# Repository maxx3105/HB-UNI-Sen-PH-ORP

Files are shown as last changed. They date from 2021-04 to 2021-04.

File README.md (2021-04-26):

# HB-UNI-Sen-PH-ORP
HomeMatic PH- und Redox-Sensor

Dieses Projekt basiert auf der Arbeit von [pa-pa](https://github.com/pa-pa/AskSinPP) ,[Jérôme](https://github.com/jp112sdl/Beispiel_AskSinPP).

# Hardware

### Bauteile

Bauteile                   | Bezeichnung          | Anzahl | Kommentar   | 
-------------------------- | -------------------- | ------ | ----------- | 
R1,R2                      | 30K Ohm              |   2    |             |
R3                         | 75K Ohm              |   1    |             |
R4                         | 1,5K Ohm             |   1    |             |
R5,R6                      | 10K Ohm              |   2    |             |
SR1                        | 1K Ohm               |   1    |  [ELV.de](https://de.elv.com/sicherungswiderstand-1k-091814?fs=1418091890)           |
C1,C2                      | 150 µF               |   2    |             |
C3,C4,C6                   | 0,1 µF               |   3    |             |
C5,C7                      | 10 µF                |   2    |             |
D1                         | SMD LED Rot          |   1    |             |
SW1                        | Taster               |   1    | [Aliexpress](https://de.aliexpress.com/item/32660690016.html?spm=a2g0s.9042311.0.0.27424c4dqj9wVN)            |
PS1                        | HLK-PM01             |   1    |             |
X1                         | WAGO 236-403         |   1    |             |
U1                         | Arduino MiniPro 3,3V |   1    |             |
U2                         | CC1101               |   1    | [Aliexpress](https://de.aliexpress.com/item/32924239954.html) |
U3                         | LM2660M              |   1    |             |
U4                         | LM358M               |   1    |             |
RV1                        | Varistor             |   1    |             |

#### Sonstiges

~8,3 cm Draht als Antenne

### Programmieradapter

- 1x FTDI Programmer https://www.az-delivery.de/products/ftdi-adapter-ft232rl

# Software

https://www.arduino.cc/en/software

### Firmware

Sketch https://github.com/jp112sdl/HB-UNI-Sen-PH-ORP/blob/master/HB-UNI-Sen-PH-ORP.ino

# Bauanleitung

coming soon

# Bilder
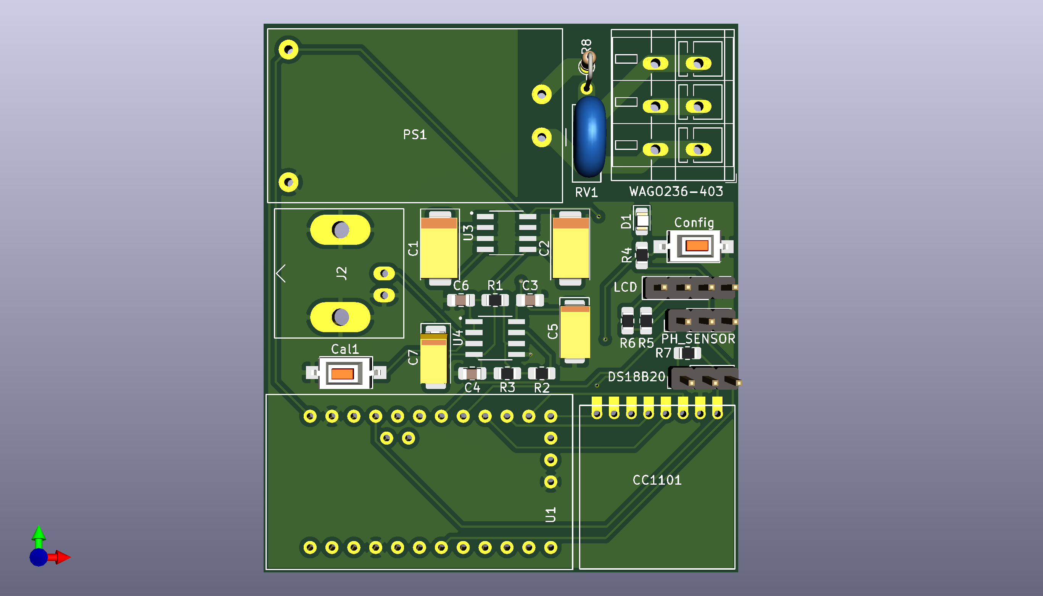
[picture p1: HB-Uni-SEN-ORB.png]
Vorderseite


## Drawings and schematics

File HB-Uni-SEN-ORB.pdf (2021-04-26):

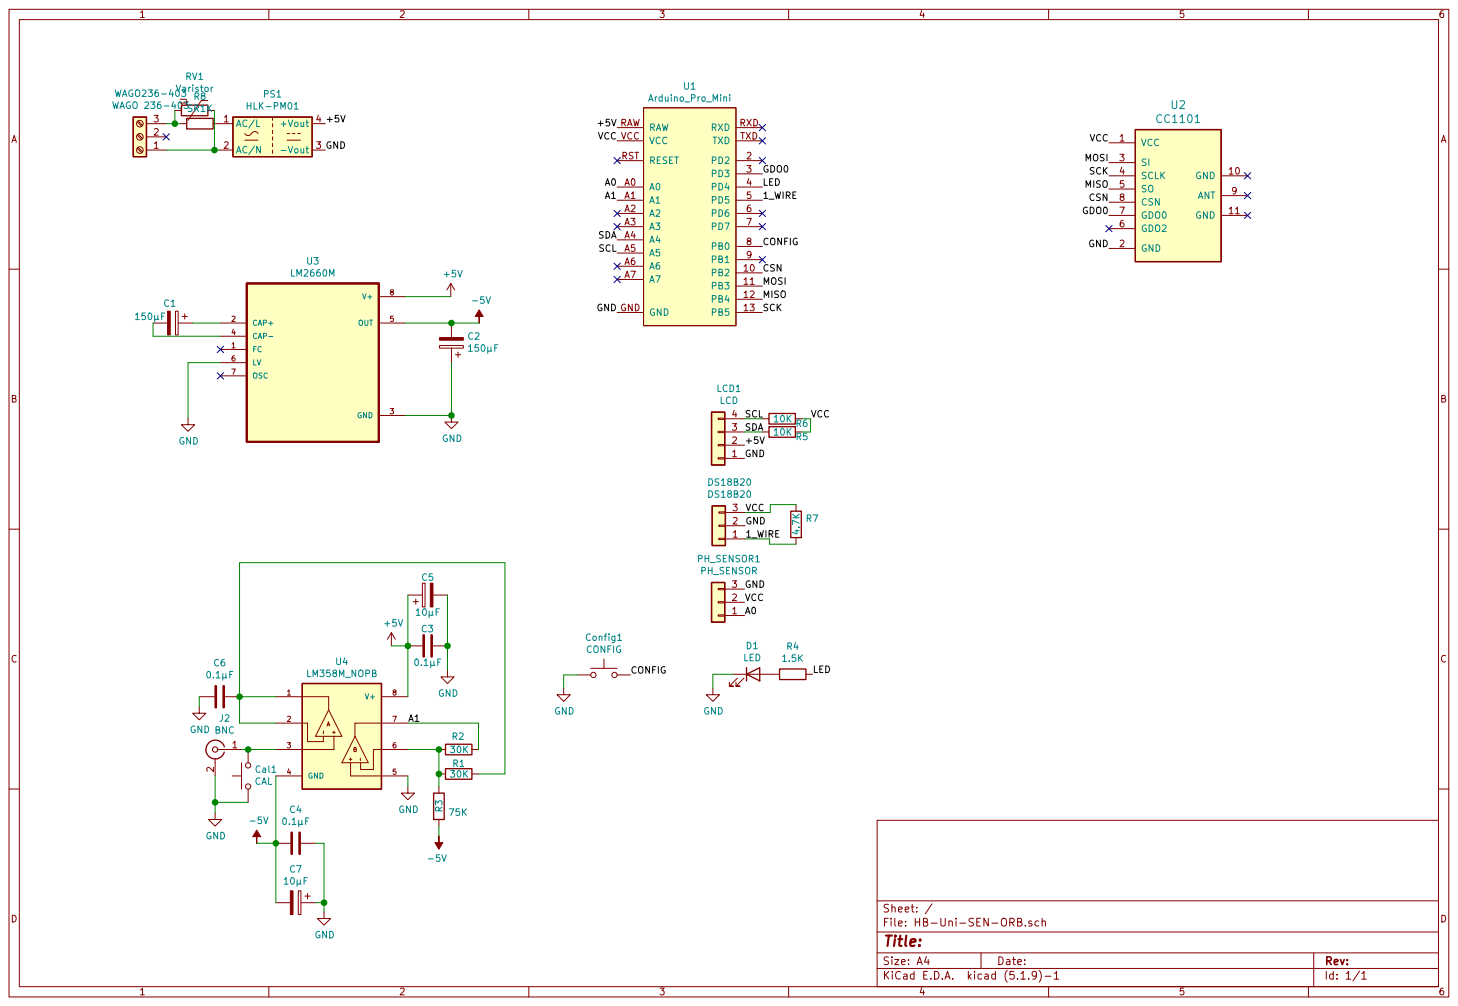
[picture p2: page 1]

VCC MOSI SCK MISO

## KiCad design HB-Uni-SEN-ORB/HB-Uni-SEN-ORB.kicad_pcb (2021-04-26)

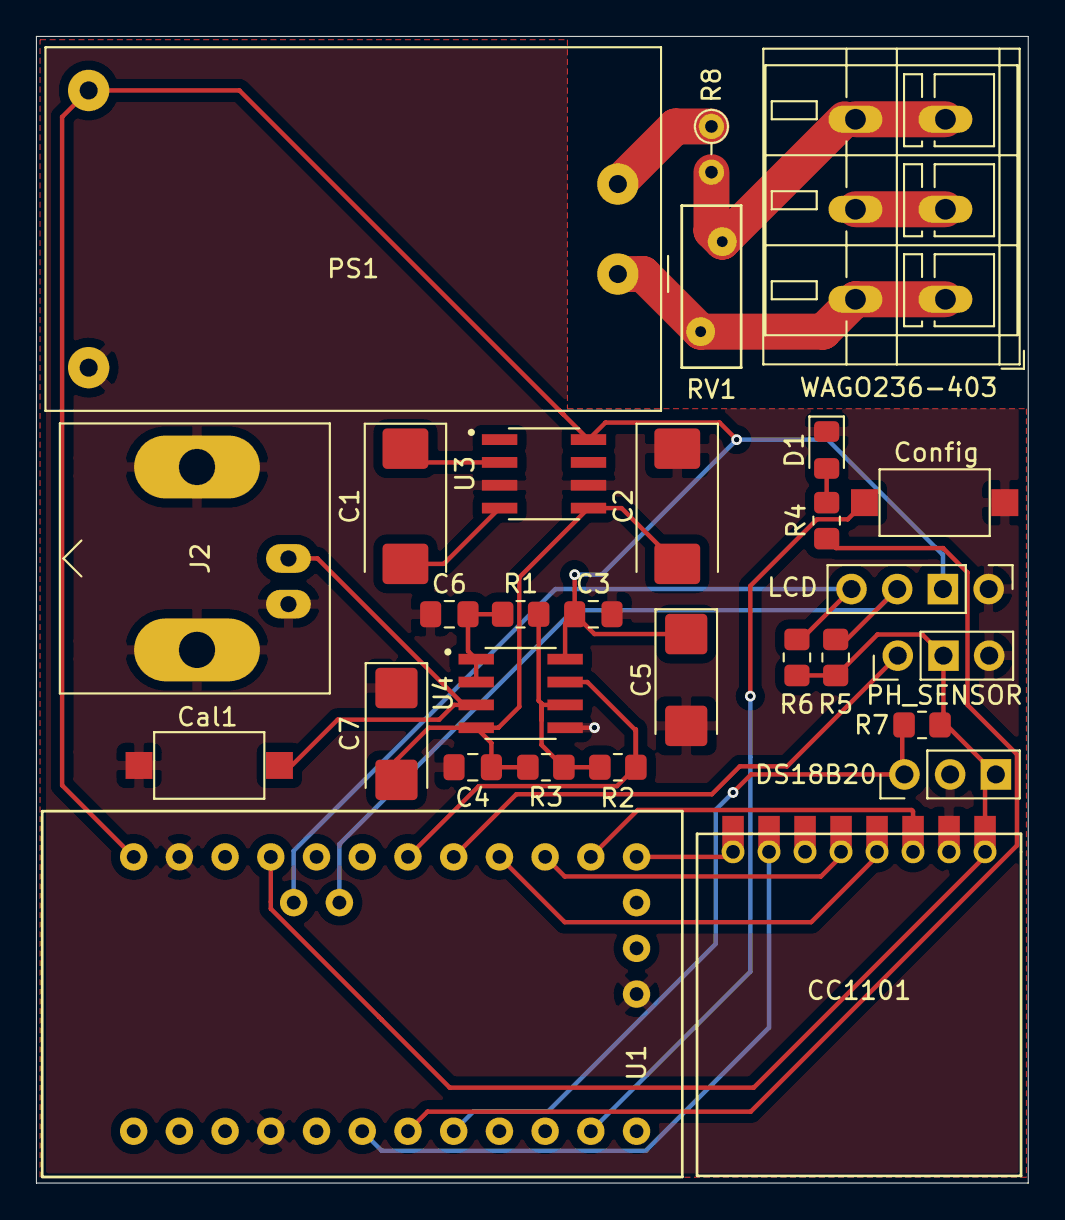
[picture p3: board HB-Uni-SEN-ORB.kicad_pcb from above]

Board: 2 copper layers, 55.1 x 63.7 mm, 29 parts (0 on the bottom side), 25 nets.

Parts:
C1, C2: 150µF; CP_EIA-7343-15_Kemet-W_Pad2.25x2.55mm_HandSolder
C3, C4, C6: 0.1µF; C_0805_2012Metric_Pad1.18x1.45mm_HandSolder
C5: 10µF; CP_EIA-6032-15_Kemet-U_Pad2.25x2.35mm_HandSolder
C7: 10µF; CP_EIA-6032-28_Kemet-C_Pad2.25x2.35mm_HandSolder
Cal1: CAL; SW_SPST_CK_RS282G05A3
Config: CONFIG; SW_SPST_CK_RS282G05A3
D1: LED; LED_0805_2012Metric_Pad1.15x1.40mm_HandSolder
DS18B20: DS18B20; PinHeader_1x03_P2.54mm_Vertical
J2: BNC; BNC_Amphenol_B6252HB-NPP3G-50_Horizontal
LCD: LCD; PinHeader_1x04_P2.54mm_Vertical
PH_SENSOR: PH_SENSOR; PinHeader_1x03_P2.54mm_Vertical
PS1: HLK-PM01; Converter_ACDC_HiLink_HLK-PMxx
R1, R2: 30K; R_0805_2012Metric_Pad1.20x1.40mm_HandSolder
R3: 75K; R_0805_2012Metric_Pad1.20x1.40mm_HandSolder
R4: 1.5K; R_0805_2012Metric_Pad1.20x1.40mm_HandSolder
R5, R6: 10K; R_0805_2012Metric_Pad1.20x1.40mm_HandSolder
R7: 4.7K; R_0805_2012Metric_Pad1.20x1.40mm_HandSolder
R8: SR1K; R_Axial_DIN0204_L3.6mm_D1.6mm_P2.54mm_Vertical
RV1: Varistor; RV_Disc_D9mm_W3.3mm_P5mm
U1: Arduino_Pro_Mini
U2: CC1101; CC1101_SMD_THT_Ohne_Ant
U3: LM2660M; SOIC127P599X175-8N
U4: LM358M_NOPB; SOIC127P599X175-8N
WAGO236-403: WAGO 236-403; TerminalBlock_WAGO_236-403_1x03_P5.00mm_45Degree

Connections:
+5V: C3.1, C5.1, LCD.2, PS1.4, U1.RAW, U3.8, U4.8
-5V: C2.2, C4.1, C7.2, R3.2, U3.5, U4.4
/1_WIRE: DS18B20.1, R7.2, U1.5
/A0: PH_SENSOR.1, U1.A0
/A1: R2.2, U1.A1, U4.7
/CONFIG: Config.2, U1.8
/CSN: U1.10, U2.8
/GDO0: U1.3, U2.7
/LED: R4.2, U1.4
/MISO: U1.12, U2.5
/MOSI: U1.11, U2.3
/SCK: U1.13, U2.4
/SCL: LCD.4, R6.1, U1.A5
/SDA: LCD.3, R5.1, U1.A4
/VCC: DS18B20.3, PH_SENSOR.2, R5.2, R6.2, R7.1, U1.VCC, U2.1
GND: C2.1, C3.2, C4.2, C5.2, C6.1, C7.1, Cal1.1, Config.1, D1.1, DS18B20.2, J2.2, LCD.1, PH_SENSOR.3, PS1.3, U1.GND, U2.2, U3.3, U3.6, U4.5
unnamed: C1.1, U3.2
unnamed: C1.2, U3.4
unnamed: C6.2, R1.2, U4.1, U4.2
unnamed: Cal1.2, J2.1, U4.3
unnamed: D1.2, R4.1
unnamed: PS1.2, R8.1
unnamed: PS1.1, RV1.1, WAGO236-403.1
unnamed: R1.1, R2.1, R3.1, U4.6
unnamed: R8.2, RV1.2, WAGO236-403.3

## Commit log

2021-04-26 Update README.md
    Add I2C Pullup
2021-04-26 Add files via upload
    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
    [HB-Uni-SEN-ORB-B_Cu.gbr, HB-Uni-SEN-ORB-B_Mask.gbr, HB-Uni-SEN-ORB-B_Paste.gbr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]
